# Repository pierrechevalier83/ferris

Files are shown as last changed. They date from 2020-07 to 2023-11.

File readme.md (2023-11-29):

Meet Ferris, a minimalistic keyboard
====================================

Named after the Rustlang mascot, Ferris is a 34-key split keyboard that tries to be about as cute as its namesake.

Ferris

Ferris is a collection of minimalistic keyboards that each focus on delivering a small set of features (mostly, typing) well.

It is fully Open-Source: the kicad files are released under [the solderpad license, version 2.1](LICENSE). The firmware, contributed to [the QMK project](https://github.com/qmk/qmk_firmware/) is released under the GPL.
The software in this repository (mostly scripts) is released under the GPL. The documentation for this project has been released to the public domain under the Creative Commons terms, specifically CC0.

The Ferris is certified by the Open Source Hardware Alliance (OSHWA).
* [Ferris 0.1: UK000013](https://certification.oshwa.org/uk000013.html)
* [Ferris 0.2: UK000027](https://certification.oshwa.org/uk000027.html)

Status
------

|  |  |
|--|--|

Design philosophy
-----------------

The Ferris was designed around this set of goals:
* Comfort
* Aesthetics
* Portability
* Ease of assembly
* Low-Cost
* Low-Profile
* 34 keys
* Hackable
* USB-C
* No compromise

and this set of non-goals:
* Reversible PCB used for both hands
* Pro-micro/Elite C/Proton C support
* Hot-Swap support
* Multi-switches support
* Support for any feature (RGB, OLED, encoders, ...) that is not of interest to the user

You may read more about how each feature (and mostly lack thereof) contributes to these goals [in this write up](docs/design_philosophy.md) once described as "overly long and almost pretentious" :)

Versions and variants
-----------------

There are currently two versions of the Ferris:
* [v0.1](0.1/readme.md) used an atmega32u4 microcontroller.
    * [Base variant](0.1/base/readme.md) (Choc switches with MX spacing)
    * [Ferris Low](0.1/low/readme.md) (Choc mini)
    * [Ferris High](0.1/high/readme.md) (MX switches)
    * [Ferris Compact](0.1/compact/readme.md) (Choc switches with choc spacing)
* [v0.2](0.2/readme.md) is in advanced prototyping stage and uses an Arm chip (STM32F072CBT6) which is more capable and cheaper than the atmega32u4. v0.2 also adds better ESD protection. The plan for v0.2 is to eventually offer full rust firmware as an alternative to qmk.
    * [Ferris Bling](0.2/bling/readme.md) (Choc, Choc spacing, packed with features)
    * [Ferris Compact](0.2/compact/readme.md) (Choc, Choc spacing, as minimalistic as the previous Ferris we all know and love)
    * [Ferris High](0.2/high/readme.md) (MX switches)
    * [Ferris Mini](0.2/mini/readme.md) (Choc mini switches with choc spacing)

How do I print one?
-------------------

* Decide which variant/version you want to print (refer to individual readme files in subdirectories for a short description of each variant).
* Download the `{version}.{variant}.release.zip` file from the latest [GitHub release on this repo](https://github.com/pierrechevalier83/ferris/releases/).

For a given version, you will find a release in this repository containing a zip file with the gerber files. This should be ready to send to a PCB manufacturer for assembly.
The repository also contains a bill of materials (bom.csv) with a list of the components you need and their reference number on LCSC.com. You may use another vendor for the components, as long as you make sure to get components that are equivalent.

How do I assemble one?
----------------------

The zip files for each release contain a file named `ibom.html`.

Open this file in a web browser for the variant you are building. It contains all the information needed to assemble
a keyboard, and is able to present it nicely in a contextual manner.

A few tips:
* Be mindful of the orientation of components.
	* The interactive bom has an option to "highlight first pin". You should match the pin drawn on the component to the side of the PCB that is highlighted. For a diode, the "first pin" is indicated with the cathode bar.
* You can change the order in which the components are displayed by clicking the column headers.
    * I like to sort the components by decreasing quantity to start with the most tedious work and end with the fun :)
* Most of the components are SMD mounted and can be soldered with a soldering iron, solder wire and flux (optional but strongly recommended).
    * If you are assembling a Ferris 0.2 - Bling, you will need a hot air station to place the LED driver chip.

And here are some key pieces of advice about soldering from my experience assembling many Ferris keyboards.
* If possible, use a wedge tip or other tip with a large enough surface. Pointy tips are harder, especially for drag soldering as they don't deliver as much heat at once.
* Don't use too much solder or you will have to wick it away and start again.
  * This especially applies to the USB C area and the small chips.
* Don't be shy on the flux: it really helps the solder flow where it should and keep away from surfaces it shouldn't go to.
* Don't use too much heat to avoid damaging the components. I've had good results with 350C for unleaded rosin core solder wire.
* Don't touch any component for too long with the iron to avoid heat damage. If you're not getting it right in a few seconds, let it cool down add more flux and try again. 
* Be sure to test every diode is properly soldered before soldering on the switches as the diodes are located under the switches and won't be accessible later on.

I took many pictures while building a Ferris 0.1 base variant.
The build log is here and may be of help:
Part 1:
[build log, part 1](https://imgur.com/gallery/jYbxkxE)
Part 2:
[build log, part 2](https://imgur.com/gallery/gs19F6E)

Where is the firmware?
----------------------

## QMK

The Ferris keyboard is powered by QMK as its main firmware.
The default keymap showcases one possible way to make a 34 keys keyboard usable and is documented [in its readme upstream](https://github.com/qmk/qmk_firmware/tree/master/keyboards/ferris/keymaps/default).
Firmware for v0.1 and the [Sweep](https://github.com/davidphilipbarr/Sweep) is already available [upstream](https://github.com/qmk/qmk_firmware/tree/master/keyboards/ferris).
Support for v0.2 should land upstream pretty soon with [this PR](https://github.com/qmk/qmk_firmware/pull/12133)
	- Support for the underglow feature is missing from this PR, but will come in a subsequent PR. It works for me locally :)

## ZMK

Support for v0.2 is also coming to upstream zmk with [this PR](https://github.com/zmkfirmware/zmk/pull/642)

## Rust firmware

I plan to write rust firmware for the v0.2 variants of the Ferris, eventually. Progress will be tracked in [this issue](https://github.com/pierrechevalier83/ferris/issues/2)

Automation
---

The philosophy of designing many simple keyboards rather than one versatile one which is slightly less good for any set of features results in an explosion in the number of designs one has to maintain.

## GitHub Actions

The keep this manageable, I have automated a number of steps such as [checking the Design Rules and the Electrical Rules](https://github.com/pierrechevalier83/ferris/actions/workflows/ci.yml) for each PCB on every commit push, and [generating release artifacts](https://github.com/pierrechevalier83/ferris/actions/workflows/release.yml) when a tag is pushed.

## Manually running within docker

Because GitHub actions perform these steps automatically, you shouldn't need to make use of the build system yourself, but for maintainers or curious bystanders, here is the workflow:

```
./automation/configure.py
```
Will generate a file named `build.ninja` in the root of the repository.

Then, running:
```
./automation/ninja.sh
```
will run `ninja` in [the ferris_automation docker container](https://hub.docker.com/repository/docker/pierrechevalier83/ferris_automation) which I published to dockerhub. This means minimal local setup is needed (basically, make sure you are able to run docker) as the specific tools are already contained in that docker image.
This will produce all build and release artifacts in a local directory called `build`.

## Running on the local system

If for a reason or another, you would prefer to run all of the tools locally rather than in `docker`, you may read the [ferris_automation Dockerfile](automation/Dockerfile) for inspiration and install the same software with the steps that work best on your platform.
In that case, docker will still be needed for some steps as it ensured [`kicad_cli`](https://github.com/pierrechevalier83/kicad_cli) can do its hackish UI manipulation in a known environment.

## Updating the `ferris_automation` docker image

When some of the scripts change in a way that will affect the `ferris_automation` docker container, I need to publish a new version.
This could be done as a GitHub action, but for now it is done manually with the following steps:

From the repo root:
```
docker build -t pierrechevalier83/ferris_automation:latest automation
docker push pierrechevalier83/ferris_automation:latest
```

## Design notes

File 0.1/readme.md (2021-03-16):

Ferris 0.1
===

Ferris 0.1 family

The 0.1 variants of the Ferris generally share the same underlying PCB design,
with varying functionalities to cater to different tastes.

The left hand uses an Atmega32u4 chip with an external crystal connected to the
computer via USB-C.

The right hand is connected to the left hand using a 4 poles TRRS Jack cable.
On the right PCB, there is a passive I/O expander (the MCP23017) which allows to
handle the input from the 5 by 4 switch matrix while only needing 4 pins (for i2c)
between halves.

Four variants were designed, printed and verified to work:
* [Base variant](base/readme.md) (Choc switches with MX spacing)
* [Ferris Low](low/readme.md) (Choc mini)
* [Ferris High](high/readme.md) (MX switches)
* [Ferris Compact](compact/readme.md) (Choc switches with choc spacing)

Note that the 0.1 design does not include any protection against electrostatic discharge.

For that reason, it is recommended to favour the 0.2 designs except if you really prefer
one of the 0.1 variants for some specific reason (for instance, you may have spare
Atmega32u4 chips on hand).

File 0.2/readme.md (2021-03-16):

Ferris 0.2
===

Ferris Bling
Ferris Bling Silk

The 0.2 variants of the Ferris generally share the same hardware, although the
Ferris bling has additional circuitry to offer RGB underglow.

Like the 0.1 designs, multiple variants are available to cater for different tastes.

The left hand uses an arm chip (STM32F072) as well as components to protect the board
against electrostatic discharge.

The right hand is connected to the left hand using a 4 poles TRRS Jack cable.
On the right PCB, there is a passive I/O expander (the MCP23017) which allows to
handle the input from the 5 by 4 switch matrix while only needing 4 pins (for i2c)
between halves.

Four variants were designed. Not all were tested yet. See subdirectories for individual
status
* [Ferris Bling](bling/readme.md) (Choc, Choc spacing, packed with features)
* [Ferris Compact](compact/readme.md) (Choc, Choc spacing, as minimalistic as the previous Ferris we all know and love)
* [Ferris High](high/readme.md) (MX switches)
* [Ferris Mini](mini/readme.md) (Choc mini switches with choc spacing)

If there is a combination of features that you are interested in and none of these variants offer,
feel free to raise an issue or a PR :)

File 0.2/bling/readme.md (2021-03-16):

# Ferris 0.2 - Bling

By design, most Ferris variants come with an extremely limited set of features.
"It's just a keyboard"

The Bling breaks away from this tradition to serve users who like a little bit
of "bling" in their life :)

Ferris Bling
Ferris Bling Silk

## Specific features:
* Choc switches (PG 1350)
* Choc spacing (18x17mm)
* Width: 10.4 cm
* Height: 9.0 cm
* Height: 1.5 cm (from desk to top of keycap with MBK switch and 2mm rubber bumper)
* Support for case (with mounting holes)
* Support for tenting puck
* RGB underglow

## Hardware status:
Working boards were produced.

## Firmware status:
* Support coming to upstream qmk with [this PR](https://github.com/qmk/qmk_firmware/pull/12133)
	* Support for the underglow feature is missing from this PR, but will come in a subsequent PR. It works for me :)
* Support coming to upstream zmk with [this PR](https://github.com/zmkfirmware/zmk/pull/642)
Plan to write rust firmware for it eventually tracked in [this issue](https://github.com/pierrechevalier83/ferris/issues/2)

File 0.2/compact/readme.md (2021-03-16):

# Ferris 0.2 - Compact

The Ferris 0.2 compact is a straight update from the 0.1 compact, which maintains
the initial minimalist instincts.

Its form factor is the same as the Ferris Bling, except it gets to save about 2mm
in the `y` dimension as mounting holes are removed.

Ferris 0.2 Compact

## Specific features:
* Choc switches (PG 1350)
* Choc spacing (18x17mm)
* Width: 10.4 cm
* Height: 8.8 cm
* Height: 1.5 cm (from desk to top of keycap with MBK switch and 2mm rubber bumper)

## Hardware status:
Working boards are yet to be printed and tested.

## Firmware status:
* Support coming to upstream qmk with [this PR](https://github.com/qmk/qmk_firmware/pull/12133)
* Support coming to upstream zmk with [this PR](https://github.com/zmkfirmware/zmk/pull/642)
* Plan to write rust firmware for it eventually tracked in [this issue](https://github.com/pierrechevalier83/ferris/issues/2)

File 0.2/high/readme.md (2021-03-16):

# Ferris 0.2 - High

The Ferris 0.2 High is a simple port from the 0.1 High with a similarly reduced number of features.
It's the Ferris with MX footprints for those who want to use the latest hardware :)
Ferris 0.2 Compact

## Specific features:
* MX switches
* Width: 10.9 cm
* Height: 9.6 cm
* Depth: 2.4 cm (from desk to top of keycap with BSP keycaps and 2mm rubber bumper)

## Hardware status:
Working boards are yet to be printed and tested.

## Firmware status:
* Support coming to upstream qmk with [this PR](https://github.com/qmk/qmk_firmware/pull/12133)
* Support coming to upstream zmk with [this PR](https://github.com/zmkfirmware/zmk/pull/642)
* Plan to write rust firmware for it eventually tracked in [this issue](https://github.com/pierrechevalier83/ferris/issues/2)
Support coming to upstream qmk with [this PR](https://github.com/qmk/qmk_firmware/pull/12133)
Support coming to upstream zmk with [this PR](https://github.com/zmkfirmware/zmk/pull/642)
Plan to write rust firmware for it eventually tracked in [this issue](https://github.com/pierrechevalier83/ferris/issues/2)

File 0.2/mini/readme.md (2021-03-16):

# Ferris 0.2 - Mini

The Ferris 0.2 mini is the tiniest Ferris in all dimensions:
* It uses choc mini switches, like the Ferris 0.1 Low to reduce the keyboard's depth.
* It uses choc spacing between keys, like the Ferris 0.1 and 0.2 compact.
* It has no extra feature needing extra space.

Reminder that like for the Ferris 0.1 low, this keyboard uses uncommon and less readily
available "choc mini" switches that can be acquired from Kailh's store on AliExpress:
* [Listing for choc mini white (clicky) switches](https://www.aliexpress.com/item/32989908397.html?spm=2114.12010612.8148356.16.41f639a68SKHzM)
* [Listing for choc mini brown (tactile) and black (linear) switches](https://www.aliexpress.com/item/4000277394324.html?spm=2114.12010612.8148356.42.194a7aebEvJRzh)

Ferris 0.2 Mini

## Specific features:
* Choc mini switches (PG 1232)
* Choc switches (PG 1350)
* Choc spacing (18x17mm)
* Width: 10.4 cm
* Height: 8.8 cm
* Height: 1.2 cm (from desk to top of keycap with MBK switch and 2mm rubber bumper)

## Hardware status:
Working boards are yet to be printed and tested.

## Firmware status:
* Support coming to upstream qmk with [this PR](https://github.com/qmk/qmk_firmware/pull/12133)
* Support coming to upstream zmk with [this PR](https://github.com/zmkfirmware/zmk/pull/642)
* Plan to write rust firmware for it eventually tracked in [this issue](https://github.com/pierrechevalier83/ferris/issues/2)

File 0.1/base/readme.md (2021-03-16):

# Ferris 0.1 - Base

This is the first ever iteration of the Ferris keyboard: a plain pcb with support for choc switches, and the same layout as the Kyria (but limited to 34 keys).

Base variant
Base variant silk

## Specific features:
* Choc switches (PG 1350)
* MX Spacing (19x19mm)
* Width: 10.9 cm
* Height: 9.6 cm
* Height: 1.5 cm (from desk to top of keycap with MBK switch and 2mm rubber bumper)

## Hardware status:
Working boards were produced.

## Firmware status:
Supported in [upstream qmk](https://github.com/qmk/qmk_firmware/tree/master/keyboards/ferris/0_1)

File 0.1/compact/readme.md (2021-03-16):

# Ferris 0.1 - Compact

As minimalist as the Ferris 0.1 - base, but featuring choc spacing instead of MX spacing,
resulting in an even smaller keyboard.

The keycaps availability for choc with choc spacing is less than that of choc switches
with MX spacing, so be sure to pay attention to the switches you are getting.

The MBK switches (pictured) are recommended as they are widely regarded as the best choc
switches for choc spaced boards.

Ferris Compact
Ferris Compact silk

## Specific features:
* Choc switches (PG 1350)
* Choc Spacing (17x18mm)
* Width: 10.4 cm
* Height: 8.8 cm
* Depth: 1.5 cm (from desk to top of keycap with MBK and 2mm rubber bumper)

## Hardware status:
Working boards were produced.

## Firmware status:
Supported in [upstream qmk](https://github.com/qmk/qmk_firmware/tree/master/keyboards/ferris/0_1)

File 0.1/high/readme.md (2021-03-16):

# Ferris 0.1 - High

The Ferris high is designed for people who like a low-profile and "no-frill" keyboard,
but like the feel of MX switches, or the keycaps availability for these more common switches.

Ferris High
Ferris High silk

## Specific features:
* MX switches
* Width: 10.9 cm
* Height: 9.6 cm
* Depth: 2.4 cm (from desk to top of keycap with BSP keycaps and 2mm rubber bumper)

## Hardware status:
Working boards were produced.

## Firmware status:
Supported in [upstream qmk](https://github.com/qmk/qmk_firmware/tree/master/keyboards/ferris/0_1)

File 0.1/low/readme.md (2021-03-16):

# Ferris 0.1 - Base

Ferris Low
Ferris Low silk

The Ferris low is similar to the 0.1 base variant, but supports choc mini switches, which are even lower profile than choc switches.

These switches are not commonly available and are more expensive than normal choc switches, but can be acquired from Kailh's store on AliExpress:
* [Listing for choc mini white (clicky) switches](https://www.aliexpress.com/item/32989908397.html?spm=2114.12010612.8148356.16.41f639a68SKHzM)
* [Listing for choc mini brown (tactile) and black (linear) switches](https://www.aliexpress.com/item/4000277394324.html?spm=2114.12010612.8148356.42.194a7aebEvJRzh)

## Specific features:
* Choc mini switches (PG 1232)
* MX Spacing (19x19mm)
* Width: 10.9 cm
* Height: 9.6 cm
* Height: 1.2 cm (from desk to top of keycap with MBK switch and 2mm rubber bumper)

## Hardware status:
Working boards were produced.

## Firmware status:
Supported in [upstream qmk](https://github.com/qmk/qmk_firmware/tree/master/keyboards/ferris/0_1)

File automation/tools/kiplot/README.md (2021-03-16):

# KiPlot

KiPlot is a program which helps you to plot your KiCad PCBs to output
formats easily, repeatable, and most of all, scriptably. This means you
can use a Makefile to export your KiCad PCBs just as needed.

For example, it's common that you might want for each board rev:

* Check DRC one last time (currently not possible)
* Gerbers, drills and drill maps for a fab in their favourite format
* Fab docs for the assembler
* Pick and place files

You want to do this in a one-touch way, and make sure everything you need to
do so it securely saved in version control, not on the back of an old
datasheet.

KiPlot lets you do this.

As a side effect of providing a scriptable plot driver for KiCad, KiPlot also
allows functional testing of KiCad plot functions, which would otherwise be
somewhat unwieldy to write.

## Using KiPlot

You can call `kiplot` directly, passing a PCB file and a config file:

```
-b $(PCB) -c $(KIPLOT_CFG) -v
```

A simple target can be added to your `makefile`, so you can just run
`make pcb_files` or integrate into your current build process.

```
pcb_files:
    kiplot -b $(PCB) -c $(KIPLOT_CFG) -v
```

## Installing

### Set up a virtualenv (if you installed KiCad normally)

If you installed KiCad from a package manager, or you used `make install`,
you probably have the packages and libraries on you system paths.

```
virtualenv --python /usr/bin/python2.7 --system-site-packages ~/venv/kiplot
```

### Set up a virtualenv (if you installed KiCad locally)

If the `pcbnew` Python package is *not* installed at a system level (e.g. if
you are building locally and not installing to the system, you should not
need any system packages:

```
virtualenv --python /usr/bin/python2.7 ~/venv/kiplot
```
However, you must make sure `pcbnew` is accessible to KiPlot.
You might need to add it to the `PYTHONPATH`.

You might also need to set `LD_LIBRARY_PATH` (you need to be able to load
`libkicad_3dsg.so`).

For example, if you installed in `~/local/kicad`, you might have:

```
export PYTHONPATH=~/local/kicad/lib/python2.7/site-packages
export LD_LIBRARY_PATH=~/local/kicad/lib64
```

### Install KiPlot to the virtualenv

Activate the virtualenv:

```
source ~/venv/kiplot/bin/activate
```

Install `kiplot` with `pip -e`:

```
cd path/to/kiplot
pip install -e .
```

## Testing

There are some tests. Run them with pytest:

```
pytest
```

# TODO list

There are some things that still need work:

* DRC checking - that can't be done over the Python interface yet. If/when
  this is added to KiCad, KiPlot will be able to also be used for DRC
  functional tests instead of a complex additonal test harness in C++.

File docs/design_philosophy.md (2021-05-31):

Design philosophy
=================

Goals:
------
* Comfort
* Aesthetics
* Portability
* Ease of assembly
* Low-Cost
* Low-Profile
* 34 keys
* Hackable
* USB-C
* No compromise

Non-Goals:
----------
* Reversible PCB used for both hands
* Pro-micro/Elite C/Proton C support
* Hot-Swap support
* Multi-switches support
* Support for any feature (RGB, OLED, encoders, ...) that is not of interest to the user

Philosophy:
-----------
Most boards provide many features that the Ferris does not provide. The most basic example would be MX switch support. MX switches are the Lingua Franca of switches and footprints supporting both MX and choc switches are readily available. It almost seems silly not to provide MX compatibility for those users who may desire it.
This specific example illustrates a philosophical difference between the Ferris and most other boards: the Ferris is built around the "Keep It Simple, Stupid" philosophy present in Arch Linux and other software projects. If the user doesn't need a feature, do not offer it and the trade-offs that go with it. The user knows better. If they want that feature, they can add it themselves. There is nothing wrong with MX switches, but when supporting both MX and chocs, a couple of things happen: The board contains unnecessary holes, which compromises on the aesthetics goal. The choc or the MX switches end up upside down, which again compromises with the aesthetics.

By following these guiding principles, we end up with a clean design that could be modified as needed to adapt any other set of user requirements.

Comfort:
--------
On the Ferris, the keys are layed out in the same way as on the [Kyria](https://splitkb.com/products/kyria-pcb-kit), with the outer column, the two inner, the outer and the two upper thumb keys removed. I have found this layout to be extremely pleasant to daily drive and plan to use the ferris as a companion to the Kyria, which means that sharing the keys layout will help my fingers feel at home on the Ferris.
While exploring my taste on the Kyria, I also discovered I found light linear switches to be very comfortable for me. I plan to bring this to the next level by exploring the lighter Kailh choc linear switches on this board. These can be quite a bit lighter than the gateron clears that I daily drive. I am expecting for this to result in improved ergonomics.
Given the relatively high profile of my Kyria board with its case, I sculpted a pair of wrist rests to go with it which allows me to type comfortably on it. By making the Ferris low profile, I am hoping to get a similar amount of comfort without a need for wrist rests.
Limiting the number of keys to only 34 means that all fingers can spend most of their time in their home position and only occasionally move one unit away. The pinkies need never be stretched and it is easy to find the thumbs home position as it's one out of only two options. This does assume the use of layers in the firmware to get fully fledged functionality in this form factor.

Aesthetics:
-----------
To match its minimalistic design philosophy, the Ferris adopts a minimalistic and yet interesting look.
The lines are few and clean. The traces are carefully routed with the intent to highlight the switch matrix (rows on the front, columns on the back). It's a design that doesn't hide "how the sausage is made", but that remains unobtrusive thanks to a limited number of features supported.
All the components are top-mounted for eye candy and a ferris the crab logo decorates the right hand board.
The SOD-123 diodes are tiny and live under switches in the spot that is usually reserved for the per-key backlights. This means that they are not visible once assembled.
The back is really bare, without any components or text. Only a few traces and the solder joints for the switches, TRRS jacks and the USB C connector should show. The intention is to only add a few fabric pads on the bottom side to be used as feet and protect the desk's surface from solder joints.
The silkscreen on the underside of the pcb is decorated with [the nice illustrations from @whoisaldeka on Twitter representing safe and unsafe rust](https://twitter.com/whoisaldeka/status/674465785557860353) that is licensed under CC-BY. The design was adapted for use on a PCB.

Portability:
------------
With only 34 keys, and without the added footprint of one or even two pro-micros, the Ferris is tiny and easy to pack and use on the go. It is also intended to be used without a case or wristrests, which makes the entire package able to fit in an 11x10x2 cm footprint while carrying it.

Ease of assembly:
-----------------
Most components are smd mounted, which means that they can be SMT assembled when getting the PCBs printed. All that remains is to solder in the switches, the jack and USB-C connectors.
Since the only holes present are exactly the ones needed, there is only one way where the hand-soldered components fit, so it shouldn't be possible to mount them the wrong way by mistake.
If hand-soldering the smd components, one must refer to the schematics for identifying where the resistors and capacitors go as the board is unlabelled for aesthetical reasons.

Low-Cost:
---------
With a reduced number of special features such as backlighting, OLEDs etc., costs are saved in all dimensions. By only requiring one atmega32u4 and one mcp23017, the electronic components are also very affordable, especially when comparing to an elite-C board which would be needed to get USB-C support if we had gone the route of a pro-micro compatible controller or two.
It should be possible to get 5 Ferris keyboards printed with all the components (mostly basic parts from LCSC. See the bill of materials) for well under 100$ with shipping to Europe by using the services of a PCB shop such as JLCPCB. Fancier options such as gold plated pads, nicer mask colors etc. may drive the cost up a little bit but larger orders would also drive it down.
Thanks to the small number of keys, switches and keycaps costs can also be kept quite low. Depending on specific choices, it should be possible to fully fit a board for around 50-60$ with shipping to Europe.
These low-costs make it feasible to customize the design to one's liking (for instance, adding support for hot swap socket) and run a limited run for one to a handful of interested users.

Low-Profile:
------------
All the components are top-mounted and low profile. The highest point on the keyboard should be at the tip of the Kailh choc switches, which sticks 6mm above the pcb, plus the added height of the chosen keycaps.
There are only solder joints on the bottom, so even with pads to protect the surface on which the keyboard rests, the entire board should be under 1cm thick.

34 keys:
--------
I have been using a gherkin with only thirty keys as a secondary keyboard for a few weeks. In fact, I am typing on one right now. With a well thought out keymap making heavy use of homerow modifiers, the 30 keys on the gherkin are just about enough. There are some unfortunate trade-offs, though, such as swapping a letter with the space key to allow for an easy to reach space key. Soon after I had the Kyria, I stopped using the two outer columns as the ergonomic trade-off in reaching for them was not worth avoiding one modifier. That means I was using 36 keys, which is the number I was originally aiming to keep on the Ferris. On further reflection, though, and after modifying my keymap to use some lessons from the gherkin, I am confident I can be totally comfortable without using the outer thumb keys. In fact, it can avoid accidental unhoming of the thumbs, which is a nice benefit. Benefits of this decision include a more compact overall footprint of the keyboard, a lower cost and a more interesting design for my taste (the outer profile is only composed of 3 straight lines and 3 curved lines).

Hackable:
---------
As is customary in the custom mechanical space, the keyboard's firmware can be fully customized using [QMK](https://github.com/qmk/qmk_firmware).
In addition to this, the hardware is licensed with the Solderpad license, version 2.1 which is a permissive license similar to Apache, but tailored to hardware projects.

The idea of limiting a single board to exactly one set of features goes hand in hand with the idea of creating a number of modifications of the original design to suit all tastes without ever compromising by overloading any single design.

Here are some ideas for modifications on the original design, and cute names to go with them:
* Ferris lit: Ferris with per key rgb backlight
* Ferris swap: Ferris with support for Kailh hotswap sockets
* Ferris wheel: Ferris with an encoder
* Ferris tent: Ferris with some M3 screw mounts on the side to allow tenting with Ergodox legs or equivalent
* Ferris mono: A non-split version where both sides would be connected by pcb like an Atreus
* Ferris air: Ferris with bluetooth

These are just a few ideas. The sky is the limit. Contributions welcome. I'm also happy to help to bring interesting concepts to life if there is interest.

USB-C:
------
It's 2020, people! Why is micro-usb still the defacto standard in hobbyist keyboard? Why is there such a premium for USB-C support on something like an elite-C compared to a pro-micro? USB-C all the things and let's forget about these ancient cables sooner rather than later.

No compromise:
--------------
No compromise doesn't mean: let's put all the features on one board. There are boards like this and they are great as a playground and to discover features one likes. No compromise here means: let's build the right board for a specific user profile with exactly the right set of features and nothing more. No trade-off or compromise will be needed for flexibility because flexibility can be obtained by enabling the user to create their own modification to fit their taste.

Work In Progress:
-----------------
More documentation is coming to showcase the technical aspects of the design.

This is the first board I ever designed and I haven't printed it and confirmed everything works yet, so use at your own risk until I test it.

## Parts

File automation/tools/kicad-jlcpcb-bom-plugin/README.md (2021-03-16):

# KiCad JLCPCB BOM Plugin

Export a JLCPCB Compatible BOM directly from your KiCad schematic!

## Installation

This script requires **Python 3**. If you need a Python 2 version, please get
[kicad-jlcpcb-bom-plugin version 1.0.0](https://github.com/wokwi/kicad-jlcpcb-bom-plugin/releases/tag/1.0.0) instead.

The script has been tested with KiCad 5.1.4.

1. Copy `bom_csv_jlcpcb.py` to your KiCad installation folder under the `bin/scripting/plugins` directory
2. In Eschema (the Schematics editor) go to "Tools" -> "Generate Bill of Materials", press the "+" button 
   at the bottom of the screen, and choose the plugin file you have just copied. When asked for a nickname,
   go with the default, "bom_csv_jlcpcb".

## Usage

Instructions for exporting JLCPCB BOM from KiCad's Eschema:

1. Go to "Tools" -> "Generate Bill of Materials"
2. Choose "bom_csv_jlcpcb" from the "BOM plugins" list on the left
3. Make sure the command line ends with "%O.csv" (otherwise, change "%O" into "%O.csv")
4. Click on "Generate". The BOM file should be created inside your project's directory, as a CSV file.

## Custom Fields

You can customize the script's output by adding the following fields to your components:

1. "LCSC Part" - Add this field to include an LCSC Part number in the generated BOM. e.g.: C2286 for a red LED.
2. "JLCPCB BOM" - Set this field to 0 (or "False") to omit the component from the generated BOM.

## Generating a JLCPCB CPL File

You can use the `kicad_pos_to_cpl.py` script to convert a KiCad Footprint Position (.pos) file into a CPL file
compatible with JLCPCB SMT Assembly service. The `.pos` file can be generated from Pcbnew, by going into 
"File" -> "Fabrication Outputs" -> "Footprint Position (.pos) File..." and choosing the following options:

* Format: CSV
* Units: Millimeters
* Files: Separate files for front and back

Also, make sure to uncheck "Include footprints with SMD pads even if not marked Surface Mount".

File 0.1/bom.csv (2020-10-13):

Comment | Designator | Footprint | LCSC | LCSC Part #
22p | C1,C2 | Capacitor_SMD:C_0805_2012Metric_Pad1.15x1.40mm_HandSolder |  | C1804
0.1u | C3,C4,C5,C6,C9,C10 | Capacitor_SMD:C_0805_2012Metric_Pad1.15x1.40mm_HandSolder |  | C49678
4.7u | C7 | Capacitor_SMD:C_0805_2012Metric_Pad1.15x1.40mm_HandSolder |  | C1779
1u | C8 | Capacitor_SMD:C_0805_2012Metric_Pad1.15x1.40mm_HandSolder |  | C28323
D | D0_0,D1_0,D0_1,D1_1,D0_2,D1_2,D2_0,D2_1,D2_2,D0_3,D1_3,D2_3,D0_4,D1_4,D2_4,D3_3,D3_4,D0_5,D1_5,D0_6,D1_6,D0_7,D1_7,D2_5,D2_6,D2_7,D0_8,D1_8,D2_8,D0_9,D1_9,D2_9,D3_5,D3_6 | Diode_SMD:D_SOD-123 |  | C81598
500mA | F1 | Fuse:Fuse_1206_3216Metric |  | C151162
USB C | J1 | Connector_USB:USB_C_Receptacle_HRO_TYPE-C-31-M-12 |  | C165948
TRRS | Jack1,Jack0 | kbd:TRRS-PJ-320A
10k | R1,R2,R9 | Resistor_SMD:R_0805_2012Metric_Pad1.15x1.40mm_HandSolder |  | C17414
22 | R4,R3 | Resistor_SMD:R_0805_2012Metric_Pad1.15x1.40mm_HandSolder |  | C17561
5.1K | R5,R6 | Resistor_SMD:R_0805_2012Metric_Pad1.15x1.40mm_HandSolder |  | C27834
4.7k | R7,R8 | Resistor_SMD:R_0805_2012Metric_Pad1.15x1.40mm_HandSolder |  | C17673
SW_PUSH | SW1 | Button_Switch_SMD:SW_SPST_B3U-1000P |  | C231329
ATmega32U4-AU | U1 | Package_QFP:TQFP-44_10x10mm_P0.8mm |  | C44854
MCP23017_SO | U2 | Package_SO:SOIC-28W_7.5x17.9mm_P1.27mm |  | C47023
Crystal | Y1 | Crystal:Crystal_SMD_3225-4Pin_3.2x2.5mm |  | C13738

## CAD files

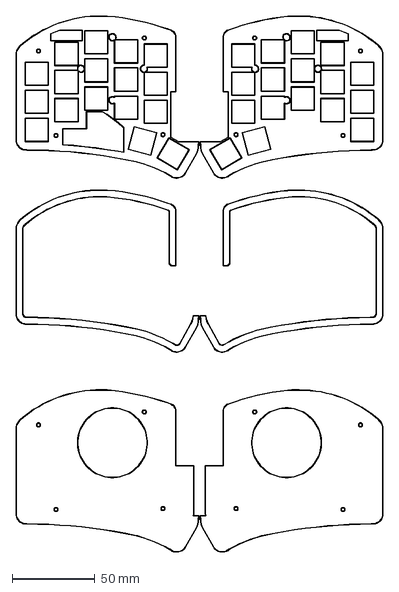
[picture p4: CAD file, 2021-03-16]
0.2/bling/#ferris_case-Edge_Cuts.dxf
221.7 x 324.2 mm

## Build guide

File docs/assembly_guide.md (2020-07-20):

Cursory assembly guide:
=======================

The cards below are designed to be printed in A6 and shipped with a Ferris kit so the people receiving a kit can easily have all the information they need at hand.

Greetings
Assembly
BoM
Keeb map
Diodes
Microcontroller
Jacks
Pinout

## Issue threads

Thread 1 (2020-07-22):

Recommended keymap

poltj18, 2020-07-22:
This keyboard looks great! Awesome work!

I'm new to QMK, layering, and small keyboards. Do you have recommended keymap for this board? I had a look for handwired/ferris in config.qmk.fm and didn't see one listed. I spent some time trying to put one together, but I don't feel like it is well optimized.

`keymap.json`
```
{"version":1,"notes":"","documentation":"\"This file is a QMK Configurator export. You can import this at <https://config.qmk.fm>. It can also be used directly with QMK's source code.\n\nTo setup your QMK environment check out the tutorial: <https://docs.qmk.fm/#/newbs>\n\nYou can convert this file to a keymap.c using this command: `qmk json2c {keymap}`\n\nYou can compile this keymap using this command: `qmk compile {keymap}`\"\n","keyboard":"handwired/ferris","keymap":"ferris_final_02","layout":"LAYOUT","layers":[["KC_Q","KC_W","KC_E","KC_R","KC_T","KC_Y","KC_U","KC_I","KC_O","KC_P","LGUI(KC_A)","LCTL_T(KC_S)","LALT(KC_D)","LT(1,KC_F)","LT(2,KC_G)","KC_H","KC_J","RALT_T(KC_K)","RCTL_T(KC_L)","RGUI_T(KC_SCLN)","KC_Z","KC_X","KC_C","KC_V","KC_B","KC_N","KC_M","KC_COMM","KC_DOT","KC_SLSH","LT(4,KC_BSPC)","LSFT_T(KC_SPC)","RSFT_T(KC_ENT)","LT(3,KC_TAB)"],["KC_NO","KC_EQL","KC_ESC","RESET","KC_NO","KC_LCBR","KC_P7","KC_P8","KC_P9","KC_RCBR","KC_NO","KC_QUOT","KC_DQUO","KC_NO","KC_NO","KC_LPRN","KC_P4","KC_P5","KC_P6","KC_RPRN","KC_NO","KC_NO","KC_NO","KC_NO","KC_NO","KC_P0","KC_P1","KC_P2","KC_P3","KC_BSLS","KC_TRNS","KC_TRNS","KC_UNDS","KC_TILD"],["KC_NO","KC_NO","KC_NO","KC_NO","KC_NO","KC_LBRC","KC_AMPR","KC_ASTR","KC_NO","KC_RBRC","KC_NO","KC_NO","KC_NO","KC_NO","KC_NO","KC_TRNS","KC_DLR","KC_PERC","KC_CIRC","KC_TRNS","KC_NO","KC_NO","KC_NO","KC_NO","KC_NO","KC_NO","KC_EXLM","KC_AT","KC_HASH","KC_PIPE","KC_TRNS","KC_TRNS","KC_MINS","KC_GRV"],["KC_NO","KC_NO","KC_NO","KC_NO","KC_NO","KC_NO","KC_F7","KC_F8","KC_F9","KC_F10","KC_LGUI","KC_LCTL","KC_LALT","KC_NO","KC_NO","KC_NO","KC_F4","KC_F5","KC_F6","KC_F11","KC_NO","KC_NO","KC_NO","KC_NO","KC_NO","KC_NO","KC_F1","KC_F2","KC_F3","KC_F12","KC_TRNS","KC_TRNS","KC_NO","KC_NO"],["KC_NO","KC_NO","KC_NO","KC_NO","KC_NO","KC_COPY","KC_UNDO","KC_NO","KC_FIND","KC_PSTE","KC_TRNS","KC_TRNS","KC_TRNS","KC_NO","KC_NO","KC_LEFT","KC_DOWN","KC_UP","KC_RGHT","KC_NO","KC_NO","KC_NO","KC_NO","KC_NO","KC_NO","KC_NO","KC_NO","KC_NO","KC_NO","KC_NO","KC_NO","KC_NO","RSFT_T(KC_ENT)","KC_TAB"]],"author":""}
```

precondition, 2020-07-27:
I am not Pierre, but allow me to chime in.

Since the Ferris is a columnar staggered board, I would recommend moving your LT(2) away from the G key and on the V key instead as it is easier to move fingers up and down than laterally.

The Ferris is also a tiny keyboard and you had the good idea to use mirrored home row mods but keep in mind that LAlt is (generally) not equivalent to Ralt aka AltGr.

Despite the easy access to Shift, you've refrained from having the need to activate a layer and shift at the same time, which is a good thing. However, it seems like you've skipped +=. You have to activate layer 1 and shift for "=". You also have no way to do `Ctrl`+`+` to zoom in.

Additionally, I can sense some misunderstanding concerning KC_TRNS (or the downward pointing triangle). It does not let through the keycode of current_layer­ - 1, it lets through the keycode of the layer below the current one in the **active layer stack**. If you activate layer 2 and try to hit "(", you'll actually get "h" because the layer 1 is not on the active layer stack. That also means that the transparent keys of your nav layer won't point to pure modifier keys, as they are laid out on layer 3, but on the home row mods of your base layer 0.

Speaking of the nav layer, I can't help but notice the distinct lack of any PGUP, PGDN, HOME, and END keys, do you never use those keys?

Finally, I can recommend replacing all your N/A keys by KC_TRNS as it would help for the times when you switch so quickly between layers while typing that you haven't fully released the layer key before typing the next letter.

pierrechevalier83, 2020-07-29:
Thanks for your interest, I still would like to do a bit of polish before opening a PR for it, but in the meantime, I've pushed my WIP keymaps to a branch on my fork of QMK.
You can find my current daily driver keymap (based on Workman with an RSTHD variant on layer 1 that I'm experimenting with) here: https://github.com/pierrechevalier83/qmk_firmware/tree/ferris_pierrec83_keymap/keyboards/handwired/ferris/keymaps/pierrec83
and my go at a "good default" here: https://github.com/pierrechevalier83/qmk_firmware/tree/ferris_pierrec83_keymap/keyboards/handwired/ferris/keymaps/default.

I do need to do a pretty render of the keymap and write a blogpost about it, but the key features are:
* Homerow modifiers and layers
* Symbol layers split over 2 layers where one hand holds down a homerow key and either the other hand or the same homerow or the other hand in one of the 10 most comfortable positions reaches for the symbol
* A Mouse layer (I have stopped using a separate mouse)
* A navigation layer with arrow keys and convenient ways to move things around in my window managers (ymmv on this one)
* A layer for function keys
* A layer for numbers with easier access to 0123 (on the homerow) as they're more common
* The highest layer is a bit of a convenience layer with enter, meta and conveniently placed keys for quick vim navigation (may need a bit of adapting for the qwerty based keymap)
* The thumbs never move away from their home position when typing as that was a source of typos for me. The non-homing thumbs are used for convenience shortcuts for me, such as changing workspaces, semi-maximizing windows, volume and brightness control... depending on the layer. For this one as well, some adaptation to one's own shortcuts would probably make sense.

pierrechevalier83, 2020-08-07:
FYI, I raised a PR to qmk with the "better default" keymap. Here is the write up with renders explaining the decisions. https://github.com/qmk/qmk_firmware/blob/94c75462148d1b9b33c2a7787c93edeacfc6fab4/keyboards/handwired/ferris/keymaps/default/readme.md

Closed 2021-03-05.

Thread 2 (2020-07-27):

Rust firmware

TeXitoi, 2020-07-27:
A Ferris keyboard that doesn't run pure rust, that't a sacrilege! :innocent:

precondition, 2020-07-27:
This is probably a good start : https://about.houqp.me/posts/rusty-c/

TeXitoi, 2020-07-27:
I'm biased, but https://github.com/TeXitoi/keyberon

pierrechevalier83, 2020-07-29:
Thanks for your interest, I definitely am interested in writing pure rust firmware for the Ferris eventually. The houqb way, while it's interesting doesn't seem like a good endgame to me as it really adds complexity on top of QMK for a tiny bit of abstraction gain.
I started by doing an atmega32u4 version for the Ferris for v0.1 as this was very well documented and it did result in a working keyboard, but this did limit my ability to write pure rust firmware for it as support for that chip is not yet in stable rust.

My understanding is that it will be easier to write pure rust for an arm version, which is one of the motivations for switching to arm in rev 0.2. In any case, I'll always offer qmk for those who want it as it's easy to write and is what everyone expects; but I will definitely look at keyberon for inspiration when is time to get rusty :smile:

TeXitoi, 2020-07-29:
STM32F0 is, IMHO, a good choice because of well supported rust crates and crystal less USB (but you need a LDO). Keyberon would work out of the box on it.

There is a crate for MCP23017 but not for PCA9539PW. It should not be too complicated to implement.

The only needed part to port a STM32F0 with a MCP23017 would be the multiple matrix handling, and it is quite straightforward as keyberon is more a library than a framework.

TeXitoi, 2020-09-04:
I see that you plan for a  Arm STM32F030F4P6TR. This MCU doesn't have USB. I think STM32F042F4P6 would be a better choice: crystal less USB, hardware DFU, and 32KB of flash (keyberon, in non optimised form with a bit more complex firmware (UART communication) is 20KB, so 16KB might be a bit small. It's a bit less cheap, but you don't need a crystal.

leshow, 2020-09-14:
This seems to be the most modern: https://gitlab.com/polymer-kb/firmware/polymer. It's based on https://gitlab.com/polymer-kb/firmware/keebrs

It uses async-await, and seems really well done.

borisfaure, 2023-04-16:
I wrote a rust firmware for the Ferris thanks to https://github.com/TeXitoi/keyberon. It is available at https://github.com/borisfaure/ferris-rs

TomzBench, 2023-04-16:
make sure to slap a big fat rust logo on it

pierrechevalier83, 2023-04-20:
> I wrote a rust firmware for the Ferris thanks to https://github.com/TeXitoi/keyberon. It is available at https://github.com/borisfaure/ferris-rs

Thank you so much for this, @borisfaure! I never ended up working on this myself, but I'm very glad it exists now thanks to you :)

tib888, 2025-02-21:
I also had the goal to write a rust firmware fom my nex keyboard, but then is accidentally found RMK - definitly worths a try: https://github.com/HaoboGu/rmk

Closed 2023-04-20.

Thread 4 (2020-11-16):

Where to buy a kit?

rmwphd, 2020-11-16:
Are kit purchases still available for this keyboard (esp. Compact, Bling, or Mini revs)?

I couldn't find a website link in the Readme.md.

MangoIV, 2020-11-27:
The newer revs are still in the prototype my stage. I guess you gotta be patient :)

mreed20, 2020-12-06:
@rmwphd A kit would definitely be more convenient, but I found that it was actually pretty easy to order the parts from https://lcsc.com (using their "BOM Tool" to upload the bill of materials, `bom.csv`) and  PCB from https://jlcpcb.com (I uploaded the PCB schematic to the website and everything else was automatic).

rmwphd, 2020-12-07:
Hmm! Thanks for the tip, Michael!

Nice last name btw ;-)

mreed20, 2020-12-07:
Many thanks, Reed :)

pierrechevalier83, 2020-12-17:
I still haven't got working firmware for my a prototypes, so I would advise for waiting it out or going with the previous arm revisions if you really want a kit now 🙂

rmwphd, 2020-12-18:
~We will watch your career with great interest.~

I'll wait patiently and maybe try kitting out an older rev for myself.

pierrechevalier83, 2021-03-25:
Hi Reed,

I know it's been a long while, but if you're still interested, I just
started a group buy for the latest version of the Ferris keyboard.

Here is a form that you can fill out if you would like to get one. I plan
to ship orders in a month or so.

https://docs.google.com/forms/d/1T0Kk4zi-_mEqnTM6SoopiEEtbMQLUm-RHTR6Tu1Jl-o

All the best,
Pierre

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

rmwphd, 2021-03-25:
Thanks for the note, Pierre! I'll be sure to sign up :-)

MoSchaub, 2021-04-05:
I signed up in the form and I was wondering if there was any confirmation email because I didn't receive anything

pierrechevalier83, 2021-04-05:
Hi Moritz,

Thanks for registering your interest.

Sorry, there isn't a confirmation email. I'll be giving updates on slack
and by email as things progress.

All the best,
Pierre

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

Closed 2020-12-18.

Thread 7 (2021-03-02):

How do I generate the gerber files?

Hendori, 2021-03-02:
I've been very interested in this keyboard (or keyboards) and I'm looking forward to building one. I however don't understand where the gerber files are or how to generate them. I can see nothing in the README.md that gives me a general clue on how to generate them. Am I missing something?
What I did was clone the repo with `git clone git@github.com:pierrechevalier83/ferris.git --recurse-submodules`
. After that it made sense to run the `ninja` command. I however keep getting `ModuleNotFoundError: No module named 'pcbnew'. Perhaps there's something wrong with my python install, I don't know. A small guide or list of commands would be nice to see if I am doing it right.

`

Hendori, 2021-03-02:
Never mind my issue. I just notice the releases where the gerber files are found. I thought I had to generate them myself with this repo, but I kept getting so many errors.

Closed 2021-03-02.

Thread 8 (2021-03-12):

No drl file in the released gerber archives

nhongooi, 2021-03-12:
I've notice there is no .drl file in the gerbers. Is that standard release? it's not an issue because I can generate it from the kicad project.

pierrechevalier83, 2021-03-15:
Thanks a lot for pointing this out @nhongooi ! It was a mis-configuration on my part. Addressing this now :smile:

Closed 2021-03-15.

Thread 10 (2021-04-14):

Upgrade Ferris High to 0.2.1

pierrechevalier83, 2021-04-14:
The Bling, Compact and Mini were touched up to ease case design by grouping components a bit closer to each other and moving the reset button to the USB area.

Do the analogous change for the high.

* It will make the experience of soldering a High more consistent with that of soldering other 0.2 Ferrises.
* It will allow for more options for case design

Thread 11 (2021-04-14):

Generate all files needed for PCBA with allpcb

pierrechevalier83, 2021-04-14:
I've placed an order for PCBA at allpcb for the bling and there had to be some back and forth with the engineer.

In particular,
* bom and pick and place file should be .xlsx
* the gerber files should contain one layer with the designators for all components. Since I don't want these refs anywhere near the silkscreen layer, consistently mark the refs as visible on F.Fab or B.Fab respectively and make sure gerbers are produced for these layers too.

- [ ] [automation] Generate correct bom file for allpcb
- [ ] [automation] Generate correct pick and place file for allpcb
- [ ] [automation] Generate gerbers for F.Fab and B.Fab layers with refs visible
- [ ] [0.2/bling] set the correct visibility for all refs on F.Fab and B.Fab
- [ ] [0.2/compact] set the correct visibility for all refs on F.Fab and B.Fab
- [ ] [0.2/mini] set the correct visibility for all refs on F.Fab and B.Fab
- [ ] [0.2/high] set the correct visibility for all refs on F.Fab and B.Fab
- [ ] [automation] Generate jlcpcp.zip and allpcb.zip with appropriate fabrication files for PCBA for each board

Closed 2021-04-14.

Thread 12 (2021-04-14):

Investigate missing elements from ibom.html generated by Github Actions

pierrechevalier83, 2021-04-14:
I've had a report that the `ibom.html` files generated by CI don't contain any parts.
Troubleshoot the issue and fix it :smiley:

laughedelic, 2021-05-22:
Are there any workarounds? I checked several releases and the latest that works for me is https://github.com/pierrechevalier83/ferris/releases/tag/ferris_release_0, I think. Later ones are empty.

Unfortunately, that last working release is a bit different from the PCB I've got, so I'm trying to get the right version of the ibom.

I tried running it locally, but the result is the same.

pierrechevalier83, 2021-05-22:
Workaround: I host the boms for all latest boards at  https://cuddlykeyboards.com/ibom.
They don't render in all browsers, though so you may need to try more than one...

laughedelic, 2021-05-23:
Thanks! This helped me a lot. It worked fine in Chrome.

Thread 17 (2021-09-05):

V0.1 TRRS jack part discontinued

ankitp4t3l, 2021-09-05:
LCSC shows part number `C12569` as discontinued. I'm on the hunt for a replacement, but thought I'd leave this note in case anyone else has already found a replacement and for me to document what I find.

keyboard-magpie, 2021-09-05:
It's a commodity part, if you search by the more generic pj-320a name you'll find them in many places.

ankitp4t3l, 2021-09-05:
I see, I was a little concerned about the differences in spacing between

1. https://datasheet.lcsc.com/szlcsc/Made-in-China-PJ-320A_C12569.pdf
1. https://www.amazon.com/uxcell-Connector-Female-Socket-PJ-320A/dp/B07KY8NMD5

but in my comparing so far the max difference is <= 0.2mm; that's okay right? :D

ankitp4t3l, 2021-09-05:
Actually (without even looking at the PCB dimensions) I gathered that
```
left to right (port edge to pin or plastic nub) mm on first (top right) image on link 1:

| Link 1 | Link 2 |
|--------+--------|
|    3.7 |    3.5 |
|   5.15 |    5.3 |
|   8.15 |    8.3 |
|   10.7 |   10.5 |
|  12.15 |   12.3 |
|   13.5 |   13.6 |

pin "row" to pin "row" spacing from top view:

| Link 1 | Link 2 |
|--------+--------|
|    4.4 |    4.4 |

are the plastic nubs centered in both? sure looks like it
```

Largest difference appears to be the diameter of the plastic nubs (0.5mm difference), but I can deal with that if it's a problem (hopefully).

Going to place my order soon!

Closed 2021-09-05.

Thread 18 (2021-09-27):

Ordering presoldered boards from PCBway

555wolfman, 2021-09-27:
I love this keyboard but i am afraid that SMD soldering is out of my reach.

Therefore my idea is to use the assembly service from PCBway / JLCPCB / Elecrow

But handling with gerber files and BOM is also out of my reach.

so my question: are any other people interested in that and has someone the skills for ordering that in a way that there is a good chance that working boards will arrive?

I can act as a proxy for EU.

Thanks in advance

Olaf

bronzehedwick, 2021-12-08:
I am in a similar boat: I am infatuated with this keyboard, and would love to get my hands on one, but my soldering skills are at n00b level, and the thought of putting everything together shakes me to my core.

So more just agreeing, but have no useful skills to offer here :/

eth0net, 2022-12-13:
Did you guys ever get anywhere with this? Stuck in the same boat now myself :D

555wolfman, 2022-12-14:
> Did you guys ever get anywhere with this? Stuck in the same boat now myself :D

No. I found a group buy for „cornish-zen“ a similar design. I get mine delivered in januar after 1 year waiting :-(

eth0net, 2023-02-15:
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

I am! Shall we take this to Discord / other messages? My details are on my profile 😃

555wolfman, 2023-02-16:
> @eth0net do you still looking for a pcb? we made a group buy and we have a presoldered one that will be ready soonish in France. The only thing that left to be soldered will be the switches (it’s the choc bling v 0.2)
>
> are you interested? (where are you based?)

I am also interested. Located in EU.

julientaq, 2023-02-17:
Folks, the group sent the remaining pcb without telling me, so the last one went away. :/

What we can do is give you the price it costs us for the whole thing and maybe we could start asking folks around for a group buy.

Wait before ordering anything as we discovered that the bom was not complete, we’ll update that in the coming week.

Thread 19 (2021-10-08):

Add a trackpoint to ferris

cmpute, 2021-10-08:
I'm attracted by ferris at the first glance, and I thought it will be the perfect killer for EDC programming/office working if a trackpoint (integrated or interface) can be added to the keyboard!

I have collected some information:
- Using thinkpad modules: [Project 1](https://deskthority.net/viewtopic.php?f=7&t=7678&start=), [Project 2](https://edryd.org/posts/tp-mk/#:~:text=steps%201%20cut%20aluminium%20plate.%20The%20first%20modification,...%207%20remove%20trackpoint.%20...%20More%20items...%20), [pin maps](https://github.com/alonswartz/trackpoint), [vendor](https://www.alibaba.com/product-detail/Namando-Laptop-TrackPoint-for-IBM-Lenovo_62315789164.html)
- Using piromoni trackball: [Kyria-based project](https://www.reddit.com/r/ErgoMechKeyboards/comments/ni1xl4/kyria_with_trackpoint_haptic_feedback_and_custom/), [module link](https://shop.pimoroni.com/products/trackball-breakout)
- Using other modules: [Thinkeys Project](https://github.com/moduloindustries/thinkeys)

I think the space left under the palm can be an option to put the trackpoint module.

hochshi, 2023-01-14:
Hay,
You can check out my crkbd variant: https://github.com/hochshi/crkbd/tree/main/corne-light-choc-mini-trackpoint.
I hope to finish designing the pcb by next week, I came to a similar conclusion and will try to connect the trackpoint controller board below the row keys, to the left of the thumb cluster.

I'm planning on supporting placing the sensor at each of the 3 thumb positions and in the  far-index column.

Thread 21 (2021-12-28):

Purpose of reset and boot circuit

toniz4, 2021-12-28:
Hello, first of all thanks for developing this awesome keyboard.

I'm trying to develop a keyboard based on the ferris schematic, but using a risc V mcu. But since I have 0 experience in elecrical engineering it has been quite the learning experience.

There is a part of the schematic that I don't quite understand, that is the part responsible for the NRST and BOOT0 pins.

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

From what I can understand, that transistor is acting like a switch and those capacitors are not necessarily for debouncing, since they are quite large, so they are there to act like a "timing capacitor", keeping BOOT0 high for some time after NRST is high, making the mcu enter bootloader mode? If my thinking is right this would impossibilitate just resetting the mcu with this switch (I'm fine with that, you can just unplug the usb cable). Or this circuit has another behaviour that I'm not accounting for?

Thanks in advance.

keyboard-magpie, 2021-12-28:
If you don’t use a circuit like this you need a button on boot0 and a button on nrst.

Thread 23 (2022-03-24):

Intermittently functional

bigtree908, 2022-03-24:
After assembling a Ferris 2.0 compact I found the ESD diode array got very hot. Only after removing the array did the keyboard work at all but only intermittently. I probably did something wrong. Do you have any troubleshooting suggestions?

pierrechevalier83, 2022-03-24:
In general, if the ESD diode array gets hot, it probably indicates a short
somewhere. I would use a voltmeter in continuity mode to try and detect any
unwanted short. Probably worth starting around the USB C connector as
that's the most fine pitched component.

Good luck with troubleshooting. Please let me know how it goes.

All the best,
Pierre

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

bigtree908, 2022-03-24:
I assembled a second with just one button, to test. I was supper careful and I've tested everything I can think of. Would there be a possible next cause?

pierrechevalier83, 2022-03-24:
There might be 2 separate issues: the ESD chip getting hot might have been
die to a short on it which went away when you unsoldered it.
In which case, the intermittent issue might be due to any other reason like
a defective processor chip or some other soldering problem.

In general, the first thing to troubleshoot is that power is correct
everywhere with a voltmeter. Maybe touch up any solder joints that look
less than perfect.

Can you describe the intermittent issue in more details? What exactly
happens?

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

bigtree908, 2022-03-24:
Ok, I think I figured out the ESD problem. I might be wrong, is it possible my usb-c socket switch the -+ data lines and that caused that issue?

I removed the ESD array. Now I have just the intermittent problem. I have just the left half built with just one button (the 0) key. When I press the button sometimes I get an '0' sometimes I don't. Sometimes I get many '0's.

When I assembled it I was careful to test each capacitor and resistor just before attaching.
When I purchased the components I had to find alternatives for some. I tried to match their values best I could.
Here are the components I was unable to find an exact, part number, match on (other than resistors/capacitors).
-Bidirectional diode
-Schottky barrier diode
-PolyFuse
-Dropout Regulator
-TVS diode array
-USB-C Jack

I really appreciate your help.

pierrechevalier83, 2022-03-24:
Ah. Thanks for describing the intermittent issue. I think that might be due to the processor polling for the Io expander from the right hand and not finding it.

You can work around it by removing the code that interacts with the right hand from the firmware for testing purposes or simply soldering the right hand and plugging it in.

If the + and - lines are mixed up, I would reflow the USB C connector as it's likely a short over there. If that doesn't do it, look for any other potential shorts along these traces.

pierrechevalier83, 2022-03-24:
Actually, + and - lines mixed up could also come from a component for which polarity matters being soldered in an incorrect orientation.

bigtree908, 2022-03-25:
Connecting the right side fixed the intermittent issue. However the right side is not responding at all. I'm going to try an audio cable that isn't spliced. Thanks for the help.

pierrechevalier83, 2022-03-25:
Just to be explicit, be sure to use a TRRS cable between the halves (with 4 poles). TRS cables that have only 3 poles aren't sufficient.

pierrechevalier83, 2022-10-11:
Also, I would advise against powering the keyboard in that state. It's
likely to date the components.

On Thu, 24 Mar 2022, 20:41 Pierre Chevalier, ***@***.***>
wrote:

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

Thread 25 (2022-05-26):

Alternatives to the I/O Exapnder

cigani, 2022-05-26:
The backorder for the I/O expander is estimated at around 80 weeks ( https://lcsc.com/product-detail/I-O-Expanders_Microchip-Tech-MCP23017-E-SO_C47023.html ) // Are their alternative chips? I noticed the same issue with the ARM chip. The 71 ( Version that doesn't have its own crystal ) is available a bit of everywhere but the 72 used in the version 0.2 is a bit on the rare side.

So are their alternatives for the I/O expander?

pierrechevalier83, 2022-05-26:
Hi,

I'm pretty sure I have some of the IO expanders left. Probably also have
PCBs. I'll confirm later today or tomorrow once I'm home and let you know.

All the best,
Pierre

On Thu, 26 May 2022, 14:33 Michael Jaquier, ***@***.***>
wrote:

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

cigani, 2022-05-26:
Hey if you have them and can ship to Europe -- I'll happily buy the stocks you have however you want to arrange the payment thanks a ton :) -- If not a company here is saying they "may" get the some of the expander stock in July but I think they're optimistic. The PCBs are also giving me some issues as well -- Uploaded the Gerber zip for the 0.2.compact release to JLCPCB and got a message back from them about some issues with the Gerber requiring additional cost

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

Never got this back from them regarding other PCBs so I thought it was a curiosity // Wasn't sure if maybe the 0.2.compact Gerbers maybe had some strangeness in them?

pierrechevalier83, 2022-05-26:
The 3 designs is kind of correct: left hand, right hand, middle info card.
It's just already panelized. I'm not sure what the other comment is about.

On Thu, 26 May 2022, 17:42 Michael Jaquier, ***@***.***>
wrote:

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

cigani, 2022-05-28:
Hey any news on the PCB front? I think I managed to find an I/O expander from a fairly sketchy Alibaba seller but the PCB is still a blocker on my end // Is the problem they're mentioning about the breakaway tabs something I can edit with the gerber files? If so I'll just look into fixing it my self

pierrechevalier83, 2022-05-28:
> Hey any news on the PCB front? I think I managed to find an I/O expander from a fairly sketchy Alibaba seller but the PCB is still a blocker on my end // Is the problem they're mentioning about the breakaway tabs something I can edit with the gerber files? If so I'll just look into fixing it my self

Hi, yes, I have PCBs and IO expanders. Can you contact me here: https://www.cuddlykeyboards.com/contact-me so we can discuss details in private?

cigani, 2022-05-28:
Of course thanks mate.

cigani, 2022-06-05:
Hey I  sent you a message but haven't heard back. I assume you're busy but let me know when you have time to discuss

pierrechevalier83, 2022-06-06:
Hey, I replied to your messages that you sent with the "contact us" form on
my website, but it seems you're not receiving messages at the address you
used on the form. Can you double check?

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

iamlambda, 2023-01-17:
salut Pierre, je rencontre le meme probleme qu'OP: il n'y a plus aucun IO expander de dispo pour build ton ferris :/ Est-ce que le manque de pièce rend le projet mort? Est-ce que tu comptes faire une version avec 2 mcu pour simplifié et rendre à nouveau disponible la construction du ferris? Sur cuddly, tout est out of stock aussi :/

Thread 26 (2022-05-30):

Is fuse programming required?

yejianfengblue, 2022-05-30:
[This website](https://www.partsnotincluded.com/sparkfun-pro-micro-with-usb-a/) says building a pro micro board needs to programming the fuse bits. Is fuse programming required for ferris v0.1 (atmega32u4 mcu with fuse) and ferris 0.2 (stm32 mcu with fuse)?

keyboard-magpie, 2022-05-30:
v0.1- atmega32u4- not usually unless you buy an RC part number- most come with DFU on from the factory
v0.2- stm32- no- not at all

yejianfengblue, 2022-05-30:
Many thanks for your quick reply.

Closed 2022-05-30.

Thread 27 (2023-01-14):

Does I2C over TRRS suffers from reliability issues?

hochshi, 2023-01-14:
Hi,
I thought this would be the right place to ask this.
I'm modifying a crkdb and would like to replace one MCU with a MCP23017/8 GPIO expander.
I'm currently using the two halves of the keyboard really far apart, around one meter. Resources online suggest running I2C over one meter would cause interference between SDA and SCL and so using a TRRS is unadvisable.
For more info see: https://github.com/Koepel/How-to-use-the-Arduino-Wire-library/wiki/How-to-make-a-reliable-I2C-bus

Have you noticed any issues with that?
Do you suggest using a specific type of TRRS cable?
Have you taken these into account when choosing the pullup resistors?

Thanks

pierrechevalier83, 2023-02-16:
I'm using a pretty short cable myself, but I've used 1m long cables without any issues.
The pullup resistors are 4.7kOhm on SDA and SCL and the chips on the 0.2 versions operate at 3.3V, so the current is under 1mA (~0.7mA), which should be well within margin according to the link you shared. They say you might encounter problems above 3mA.

hochshi, 2023-02-19:
Thank you.

Closed 2023-02-16.

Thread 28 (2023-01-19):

[bling 0.2] Is RGB underglow visible throught the keycaps

robinmoussu, 2023-01-19:
With a group of friend we are planning to build ferris bling 0.2. We are looking at [those white keycaps](https://splitkb.com/collections/switches-and-keycaps/products/moergo-mcc-profile-1u-keycap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). They are translucent which let the light goes through, but is it visible on the ferris since the leds seems to be only under the pcb?

pierrechevalier83, 2023-02-16:
No, the RGBs are under the PCB and there aren't any cutouts, so translucent keycaps won't look particularly nice on the Bling.

robinmoussu, 2023-03-16:
I forgot to say thank you!

Closed 2023-02-16.

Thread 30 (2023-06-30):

Why the choice on TRRS cable ?

Velasko, 2023-06-30:
Checking at the schematics, seems like 2 pins are used for vcc and one for gnd.
Changing it to ( vcc | gnd | data | data ) would make it compatible with both trs and trrs cables and sockets.

quarthex, 2024-11-02:
I just checked the schematics.

Jack0: i2c_scl, i2c_sda, +3V3, GND
Jack1: i2c_scl_right, i2c_sda_right, VDD, GND

It looks good to me.

Velasko, 2024-11-04:
Oh, I see now.

I was actually looking into a fork of the project, which has a microcontroller on both ends, which allows that.
I suppose they kept that in order to change the original board as little as possible.

When I noticed that, I thought on creating the issue there, but noticed this also happened here. Thought it would be better to ask things here.

Thanks for the explanation and sorry for the inattentiveness.

Will close the issue as it has been clearly answered now.

Closed 2024-11-04.

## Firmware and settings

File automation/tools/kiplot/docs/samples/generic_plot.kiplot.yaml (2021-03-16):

# Example KiPlot config file
kiplot:
  version: 1

preflight:

  # one day....
  check_zone_fills: false
  run_drc: false

outputs:

  - name: 'gerbers'
    comment: "Gerbers for the board house"
    type: gerber
    dir: gerberdir
    options:
      # generic layer options
      exclude_edge_layer: false
      exclude_pads_from_silkscreen: false
      use_aux_axis_as_origin: false
      plot_sheet_reference: false
      plot_footprint_refs: true
      plot_footprint_values: true
      force_plot_invisible_refs_vals: false
      tent_vias: true
      check_zone_fills: true

      # gerber options
      line_width: 0.15
      subtract_mask_from_silk: true
      use_protel_extensions: false
      gerber_precision: 4.5
      create_gerber_job_file: true
      use_gerber_x2_attributes: true
      use_gerber_net_attributes: false

    layers:
      - layer: F.Cu
        suffix: F_Cu
      - layer: F.SilkS
        suffix: F_SilkS
      # - layer: Inner.1
      #   suffix: Inner_1

  - name: excellon_drill
    comment: "Excellon drill files"
    type: excellon
    dir: gerberdir
    options:
      metric_units: true
      pth_and_npth_single_file: true
      use_aux_axis_as_origin: false
      minimal_header: false
      mirror_y_axis: false
      report:
        filename: 'drill_report.rpt'
      map:
        type: 'pdf'

  - name: gerber drills
    comment: "Gerber drill files"
    type: gerb_drill
    dir: gerberdir
    options:
      use_aux_axis_as_origin: false

  - name: postscript
    comment: "Postscript files"
    type: ps
    dir: gerberdir
    options:
      exclude_edge_layer: false
      exclude_pads_from_silkscreen: false
      use_aux_axis_as_origin: false
      plot_sheet_reference: false
      plot_footprint_refs: true
      plot_footprint_values: true
      force_plot_invisible_refs_vals: false
      tent_vias: true
      check_zone_fills: true

      # PS options
      line_width: 0.15
      drill_marks: full
      scaling: 2
      sketch_plot: true
      scale_adjust_x: 1.0
      scale_adjust_y: 1.0
      width_adjust: 0
      mirror_plot: false
      negative_plot: false
      a4_output: true
    layers:
      - layer: F.Cu
        suffix: F_Cu
      - layer: F.Fab
        suffix: F_Fab
      # - layer: Inner.1
      #   suffix: Inner_1
      #   
  - name: DXF
    comment: "DXF files"
    type: dxf
    dir: gerberdir
    options:
      exclude_edge_layer: false
      exclude_pads_from_silkscreen: false
      use_aux_axis_as_origin: false
      plot_sheet_reference: false
      plot_footprint_refs: true
      plot_footprint_values: true
      force_plot_invisible_refs_vals: false
      tent_vias: true
      check_zone_fills: true

      # PS options
      drill_marks: full
      sketch_plot: true
      use_aux_axis_as_origin: false
      polygon_mode: true
    layers:
      - layer: F.Cu
        suffix: F_Cu
      - layer: F.Fab
        suffix: F_Fab

  - name: SVG
    comment: "SVG files"
    type: svg
    dir: gerberdir
    options:
      exclude_edge_layer: false
      exclude_pads_from_silkscreen: false
      use_aux_axis_as_origin: false
      plot_sheet_reference: false
      plot_footprint_refs: true
      plot_footprint_values: true
      force_plot_invisible_refs_vals: false
      tent_vias: true
      check_zone_fills: true

      # SVG options
      line_width: 0.25
      drill_marks: full
      mirror_plot: true
      negative_plot: true
    layers:
      - layer: F.Cu
        suffix: F_Cu
      - layer: F.Fab
        suffix: F_Fab

  - name: HPGL
    comment: "HPGL files"
    type: hpgl
    dir: gerberdir
    options:
      exclude_edge_layer: false
      exclude_pads_from_silkscreen: false
      use_aux_axis_as_origin: false
      plot_sheet_reference: false
      plot_footprint_refs: true
      plot_footprint_values: true
      force_plot_invisible_refs_vals: false
      tent_vias: true
      check_zone_fills: true

      # HPGL options
      drill_marks: full
      mirror_plot: true
      sketch_plot: true
      scaling: 0 # auto
      pen_width: 0.5
    layers:
      - layer: F.Cu
        suffix: F_Cu
      - layer: B.SilkS
        suffix: B_Silks

  - name: PDF
    comment: "PDF files"
    type: pdf
    dir: gerberdir
    options:
      exclude_edge_layer: false
      exclude_pads_from_silkscreen: false
      use_aux_axis_as_origin: false
      plot_sheet_reference: false
      plot_footprint_refs: true
      plot_footprint_values: true
      force_plot_invisible_refs_vals: false
      tent_vias: true
      check_zone_fills: true

      # PDF options
      drill_marks: small
      mirror_plot: false
      negative_plot: false
      line_width: 0.01
    layers:
      - layer: F.Cu
        suffix: F_Cu
      - layer: B.SilkS
        suffix: B_Silks

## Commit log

2020-05-30 First commit: minimalistic functional version of my idea
    Here is what I have in mind: to make a board that is great for many
    people like the Kyria, compromises must be taken.
    For instance, footprints must be versatile to allow for various types
    of switches, socketed or non-socketed etc. Supporting a board like the
    pro-micro or elite-c allows for versatility while keeping the pcb design
    a bit easier. Supporting a symmetrical layout allows for a simpler
    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
    [ferris.kicad_pcb, ferris.sch]
2020-05-30 Add Ferris copper pad and various cleanups
    Add Ferris copper pad
    Add front and back masks behind the right hand's usb area for
    consistency with the left side and to clean up a couple of traces.
    Reroute the entire highway between the atmega and the usb c area on the
    left hand.
    Add the cleaned up switches footprints to ferris.pretty and use these in
    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
    [ferris.kicad_pcb, ferris.sch]
2020-05-31 Remove all non-decorative pads in favour of proper tracing
    [ferris.kicad_pcb]
2020-05-31 Schematics: add pwr_flag symbols to pass the electric rules check
    [ferris.sch]
2020-06-01 Pick parts and generate bom and cpl
    Browse the catalog from jlppcb and match parts to the ones available.
    Change some foot prints such as mcp23017 to a different package when
    more readily available.
    [bom.csv, ferris.kicad_pcb, ferris.sch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]
2020-06-01 Rename diodes and switches to avoid conflicting use of coma in bom
    [bom.csv, ferris.sch]
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2020-06-01 Update BOM to get basic rather than extended parts and fix mistake with one of the capacitor values
    [bom.csv, ferris.kicad_pcb, ferris.sch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]
2020-06-03 Cleanup the edge cuts, move components around and clean up the tracing
    [ferris.kicad_pcb, ferris.sch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]
2020-06-03 Hide legends for diodes and reset button, minor layout tweaks
    [ferris.kicad_pcb, ferris.sch]
2020-06-04 Cleaup the edge cuts and traces some more
    [ferris.kicad_pcb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]
2020-06-04 Cleanup the traces on the right hand switch matrix
    [ferris.kicad_pcb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]
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2020-06-04 Drop outer thumb keys
    My experience on the gherkin taught me they're not necessary.
    Without them, the form factor gets smaller and the design gets a bit
    simpler and more aesthetically pleasing.
    [bom.csv, ferris.kicad_pcb, ferris.sch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]
2020-06-04 Change the matrix layout now we have less thumb keys
    [bom.csv, ferris.kicad_pcb, ferris.sch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]
2020-06-04 Cleanups and regenerate gerber files + bom + cpl
    [bom.csv, ferris.kicad_pcb, ferris.sch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]
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2020-06-06 Replace crystal with GND24 and mcu with Atmega32u4-AU
    [ferris.kicad_pcb, ferris.sch]
2020-06-06 Add a decoupling capacitor on the other side of the microchip
    [ferris.kicad_pcb, ferris.sch]
2020-06-06 Add a 10k resistor between the mcp's reset and vdd
    [ferris.kicad_pcb, ferris.sch]
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2020-06-06 Redo all the traces after learning a bit more from ai03's tutorial
    [ferris.kicad_pcb, ferris.sch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]
2020-06-07 Obsess a little bit more over the routing
    [ferris.kicad_pcb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]
2020-06-08 Fix power symbols, add fuse for USB vcc input
    [ferris.kicad_pcb, ferris.sch]
2020-06-09 Add fuse from USB's VCC input and ground zones
    [bom.csv, ferris.kicad_pcb, ferris.sch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]
2020-06-09 Improve the decoupling capacitors near the mcp
    Like for the mcu, make one of the decoupling capacitors larger as
    explained in this blogpost: https://www.autodesk.com/products/eagle/blog/what-are-decoupling-capacitors/
    [ferris.kicad_pcb]
2020-06-09 Add gnd zone near the mcp and reroute the left handside gnd wire to the bottom of the bus
    [ferris.kicad_pcb]
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2020-06-09 Left jack: reroute traces through resistors first
    I am not sure it makes a difference. Should ask around.
    [ferris.kicad_pcb]
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2020-06-11 Fix issue in vias under mcu spotted by pcb manufacturer
    [ferris.kicad_pcb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]
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2020-10-12 Delete all unnecessary files from repo root
    Many of these files where generated. The important ones where already
    duplicated under 0.1/base
    [bom.csv, ferris.kicad_pcb, ferris.sch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]
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2020-10-15 Flip the blings to respect courtyards
    [ferris.kicad_pcb]
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2020-10-15 Pull in puck footprint which doesn't trigger warnings with incorrect courtyard
2020-10-15 0.2/bling: Fix puck courtyard warnings
    [ferris.kicad_pcb]
2020-10-15 0.2/bling: use new dual broken out mcu footprint
    This allowed me to get clean ERC and DRC reports.
    [ferris.kicad_pcb, ferris.sch]
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2020-10-15 0.2/compact: import from v0.2_compact branch and update
    Use ferris_pcb_art and keyboard_footprints submodules.
    Update MCU to footprint with breakout pins.
    Fix all Electrical Rules Checker and Design Rules Checker warnings.
    [ferris.kicad_pcb, ferris.sch]
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2020-10-17 Fix unconnected pads in 0.2/high caught by DRC
    [ferris.kicad_pcb]
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2020-10-18 0.2/high: Fix missing ground fills area that my automated renders helped me spot
    [ferris.kicad_pcb]
2020-10-18 0.2/bling: Fix missing ground fills area that my automated renders helped me spot
    [ferris.kicad_pcb]
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2020-10-18 bom: generate jlc boms too
    We had to slightly alter the schematics to match the plugin's
    expectations. Adapted the interactive plugin to account for the change.
    [ferris.sch, underglow.sch]
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2020-10-24 Aim to fix wx problem for interactive bom
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2021-03-07 Run docker as current user
    This avoids all the build artifacts to be owned by the root user, which
    is inconvenient.
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2021-03-07 Remove old meson files
    These files were left over from my original attempt at producing build
    artifacts with meson.
    I later opted for my own ./configure.py script as meson didn't offer the
    flexibility needed for my use case (specifically, one rule generating
    multiple files)
2021-03-15 0.2/bling: Add human readable "Part Name" field
    Use short human readable names to describe components, such as "MCU"
    instead of "STM32F072CBT6".
    This allows us to be quite precise in the "value" field while displaying
    an easy to understand description of each component in the generated
    interactive Bill of Material.
    We can then use the same language on the BOM cards for a smooth user
    experience of assembling one's Ferris.
    [ferris.kicad_pcb, ferris.sch, underglow.sch]
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2021-03-15 Generate drill files as part of the build/release process
    * Fix a configuration issue in `.kiplot.yml` where we were asking kiplot
    to generate the drill files in an unexistent directory, preventing
    their generation
    * List the newly generated drill files as an output of the gerber rule
    Fixes https://github.com/pierrechevalier83/ferris/issues/8
2021-03-16 Design mid-profile case for the 0.2/bling
    Create a Kicad project for each plate with only edge cuts.
    This will allow generation of gerbers for printing pcb cases or dxf
    files for ordering cut acryllic.
    This design is mainly meant to be printed out of 3mm acrylic.
    [bottom_plate_with_puck.kicad_pcb, bottom_plate_without_puck.kicad_pcb, mid_plate.kicad_pcb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]
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2021-03-16 Add dummy component to each plate case
    This works around a segfault in Pcbdraw which prevents renders in the
    edge case where a PCB file has no module.
    [#ferris_case-Edge_Cuts.dxf, bottom_plate_with_puck.kicad_pcb, bottom_plate_without_puck.kicad_pcb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]
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2021-03-18 Bling: Update the puck footprint to fix silk issue
    The keyboards I ordered read "puck tenting" in the back silkscreen
    instead of "tenting puck". Looking at the footprint in
    `keyboard_footprints`, I could see that it was labelled correctly, so I
    updated the references to the footprint in the Ferris Bling's kicad
    project.
    [ferris.kicad_pcb]
2021-03-22 Bling case: make thinnest places a bit thicker
    One of the samples I received was damaged in one of the thin points.
    In person, I could see that there was a little bit of margin to make
    the design a bit more solid.
    [top_left_plate_with_puck.kicad_pcb, top_left_plate_without_puck.kicad_pcb, top_right_plate_with_puck.kicad_pcb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]
2021-03-30 Ferris compact: Update PCB to ease case design
    Perform a number of small changes to allow for creation of a symmetrical
    switch plate that can cover the MCU area and leave the USB area exposed.
    Also move components a bit further from the switches to avoid very slim
    parts of the case.
    * Move reset button to USB area
    * Layout the USB area in a more compact way
    * Bring MCU's decoupling capacitors closer to the MCU
    * Bring Components under the Jack plugs closer to each other
    * Reroute traces accordingly
    * Update version to 0.2.1 to reflect the change (silk and mini card)
    [ferris.kicad_pcb]
2021-03-30 Ferris mini: Update PCB to ease case design
    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
    [ferris.kicad_pcb]
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2021-04-03 Improve the compact/mini case for manufacturing
    * Make all edge cuts 0.1 mm
    * Make the lip for the bottom and the dampener in cork out of one piece
    * Rename the files to express the material
    [cork_spacer_and_lip.kicad_pcb, lip.kicad_pcb, metal_plate.kicad_pcb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]
2021-04-03 Ferris bling: Update PCB to ease case design
    Perform a number of small changes to help reduce the number of thin
    parts in the acrylic case design.
    Also brings consistency with the Ferris compact 0.2.1 and Ferris mini
    0.2.1 and opens the possibility for a low_profile case for the bling
    similar to what already was designed for these.
    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
    [ferris.kicad_pcb]
2021-04-04 Create template to help designing bling case
    Mark the position of everything that may matter in the design of a case
    on various comment layers, so it is easy to create different layers of
    the case with the exact same measurements.
    [template.kicad_pcb]
2021-04-04 Make Bling mid-profile case more robust
    I plan to print the top and bottom plates in 2mm acrylic, so thin parts
    will be quite fragile.
    Use the new layout of the components in the PCB to tweak the case with a
    little more rigidity.
    Also rename the files so they are a bit more readable.
    Changes:
    * Lip is now a closed shape around the USB area (more solid)
    * Lip is thicker: 5 mm in thickest point instead of 4mm previously
    * Cutouts for components are much tighter to the components
    * Remove the non-puck switch plate as it is better to give people the
    option to upgrade later if they so desire.
    [bottom_plate_no_puck.kicad_pcb, bottom_plate_puck.kicad_pcb, bottom_plate_with_puck.kicad_pcb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]
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2021-04-12 Bling: Mark the RGB LEDs as SMD components
    Without this, the generated pick and place file omits these components,
    which is problematic when ordering PCB assembly for the top and bottom
    side of the board.
    [ferris.kicad_pcb]
2021-04-14 Kiplot: Plot F.Fab and B.Fab and plot footprint references
    Partially fixes https://github.com/pierrechevalier83/ferris/issues/11
2021-04-14 Automation: add Fab layers to the gerbers
    Also ensure that changes to the pcb file or the kiplot config trigger a
    new build for the gerbers.
    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
2021-05-11 Bling case: make more space for the TRRS connector
    I had to manually trim this bit up on my prototype batch. It interferes
    with the Jack cable.
    [left_switch_plate.kicad_pcb, right_switch_plate.kicad_pcb]
